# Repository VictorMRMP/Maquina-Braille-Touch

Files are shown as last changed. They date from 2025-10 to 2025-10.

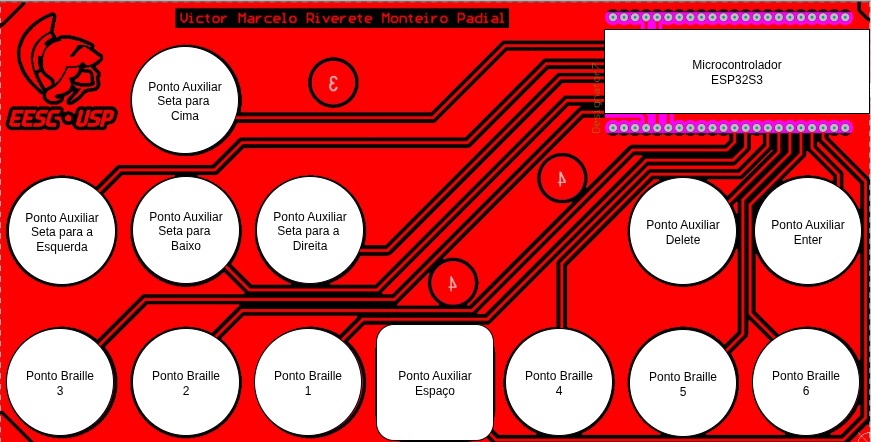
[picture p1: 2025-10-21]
Posição dos pontos.png

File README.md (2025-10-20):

# Teclado Touch Braille (TCC)

Este repositório contém o código-fonte do projeto de Trabalho de Conclusão de Curso (TCC) intitulado: **"Teclado Touch Braille para auxílio na alfabetização e navegação digital de deficientes visuais sensíveis ao toque e/ou com limitações motoras"**.

* **Autor:** Victor Marcelo Riverete Monteiro Padial
* **Microcontrolador:** ESP32-S3
* **Comunicação:** USB HID (Teclado)

## Objetivo do Projeto

O objetivo deste projeto é um teclado Braille totalmente funcional, construído com sensores capacitivos (touch) e um microcontrolador ESP32-S3. O sistema é projetado para ler as combinações de 6 pontos da cela Braille e 7 teclas auxiliares (setas, espaço, enter, apagar), convertendo-as em caracteres digitais.

O principal diferencial deste projeto é o suporte nativo à **Grafia Braille para a Língua Portuguesa**, permitindo a digitação correta de caracteres acentuados (como `á`, `é`, `ç`, `ã`) e símbolos do padrão ABNT.

## Funcionamento

O firmware utiliza o FreeRTOS do ESP32 para dividir o processamento em duas tarefas principais, rodando em núcleos separados:

1.  **`processBraille` (Núcleo 0)**: Esta tarefa é responsável por ler os 6 pinos de toque que compõem a cela Braille. Ela aguarda um tempo (`readingDelay`) para estabilizar a leitura e então processa a combinação. O código gerencia estados especiais, como "letra maiúscula" e "número", e utiliza mapas (`std::map`) para traduzir a combinação Braille no caractere correspondente.
2.  **`processAux` (Núcleo 1)**: Esta tarefa lê os 7 pinos de toque auxiliares. Ela identifica comandos de navegação (Setas), `Espaço`, `Enter` e `Apagar` e os envia diretamente como comandos de teclado.

### Suporte ao Layout ABNT

Para que o teclado enviasse caracteres acentuados do português (ABNT) corretamente, foi necessário modificar a biblioteca USB padrão do ESP32.

O projeto utiliza uma biblioteca `KeyboardUTF8` (baseada na obra de JohnWasser), que foi adaptada para usar o objeto `USBHIDKeyboard` do ESP32. Esta biblioteca utiliza uma tabela de consulta (`Keyboard_BR_1.h`) que mapeia caracteres Unicode (como `0xE1` para `á`) para a sequência correta de teclas ABNT (ex: pressionar "acento agudo", soltar, pressionar "a").

Os arquivos `USBHIDKeyboard.cpp` e `.h` originais do ESP32 foram modificados para suportar este envio no formato ABNT ao invés do US-ASCII padrão.

## Estrutura dos Arquivos

* `MaquinaBrailleTouchFinal.ino`:
    * Código principal do teclado Braille.
    * Contém a lógica de inicialização das tarefas (FreeRTOS), os mapas de caracteres Braille-para-Português, os mapas das teclas auxiliares e a lógica de processamento de toque para ambas as tarefas.
    * Instancia os objetos `USBHIDKeyboard` (nível baixo) e `KeyboardUTF8` (nível alto/ABNT).

* `TesteDeToque.ino`:
    * Um sketch auxiliar de diagnóstico.
    * Ele é usado para calibrar os sensores de toque. O código lê todos os 13 pinos capacitivos e exibe seus valores "base" e a "diferença" (delta) quando tocados, facilitando a definição dos valores de `baseCapacitance` e `thresholdTouch` usados no arquivo `.ino` principal.

* `USBHIDKeyboard.h` e `USBHIDKeyboard.cpp`:
    * **Arquivos de biblioteca modificados.**
    * Substituem os arquivos padrão da biblioteca USB do ESP32.
    * A modificação principal é a remoção do mapa de caracteres US-ASCII padrão.

* `KeyboardUTF8.h` e `KeyboardUTF8.cpp`:
    * **Novos arquivos de biblioteca.**
    * Adaptação da biblioteca `KeyboardUTF8` para ser compatível com a `USBHIDKeyboard` do ESP32.
    * Recebe um caractere Unicode (ex: 'ç') e usa as tabelas de layout para enviá-lo como comandos de teclado.

* `Keyboard_BR_1.h`:
    * **Novo arquivo de biblioteca (Layout).**
    * Contém as tabelas de consulta (lookup tables) para o layout Português-Brasil ABNT.
    * Define o código de tecla (`keycode`) e os modificadores (`MOD_SHIFT`, `MOD_ALTGR`) para cada caractere, incluindo acentos e símbolos.

## Como Usar e Instalar

1.  **Hardware:**
    * Conecte os 13 sensores capacitivos aos pinos do ESP32-S3 conforme definido nos arrays `touchPins` e `auxPins` em `MaquinaBrailleTouchFinal.ino`.

2.  **Calibração (Opcional, mas recomendado):**
    * Carregue o sketch `TesteDeToque.ino` no ESP32-S3.
    * Abra o Monitor Serial (baud 9600).
    * Anote os valores médios dos pinos sem toque (exibidos na calibração inicial). Estes serão seus valores `baseCapacitanceTouch` e `baseCapacitanceAux`.
    * Toque em cada sensor e anote o valor `Δ` (diferença). Escolha um valor seguro para o `thresholdTouch` (ex: `1000`, como no código).
    * Atualize os valores de calibração no início do `MaquinaBrailleTouchFinal.ino`.

3.  **Instalação da Biblioteca ABNT (Crucial):**
    * Encontre o diretório de instalação da biblioteca `USB` do ESP32. O caminho provável é:
        `.../ArduinoData/packages/esp32/hardware/esp32/2.0.14/libraries/USB/src`
    * **Faça backup** dos arquivos `USBHIDKeyboard.h` e `USBHIDKeyboard.cpp` originais.
    * Copie os arquivos `USBHIDKeyboard.h` e `USBHIDKeyboard.cpp` deste repositório para a pasta `src`, substituindo os originais.
    * Copie os arquivos `KeyboardUTF8.h`, `KeyboardUTF8.cpp`, e `Keyboard_BR_1.h` para esta **mesma** pasta `src`.

4.  **Carregar Firmware Principal:**
    * Abra o arquivo `MaquinaBrailleTouchFinal.ino` no seu Arduino IDE.
    * Compile e carregue o código para o ESP32-S3.
    * O dispositivo será reconhecido pelo sistema operacional como um teclado USB padrão e estará pronto para uso.

## Créditos

* A implementação do layout ABNT/UTF-8 é uma adaptação do trabalho original de **JohnWasser** (disponível em [Arduino\_KeyboardUTF8](https://github.com/JohnWasser/Arduino_KeyboardUTF8)).

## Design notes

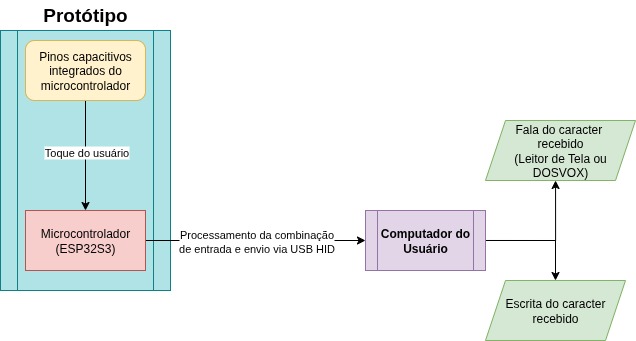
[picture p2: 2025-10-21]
Diagrama Hardware.jpeg

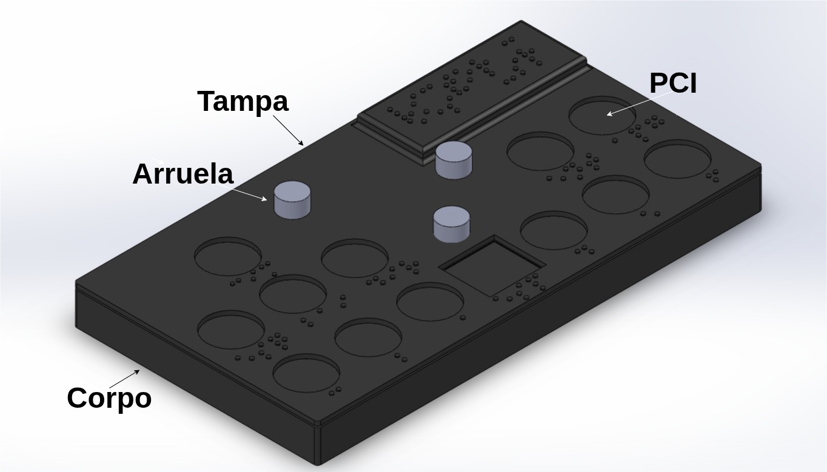
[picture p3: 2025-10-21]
Case3D.png

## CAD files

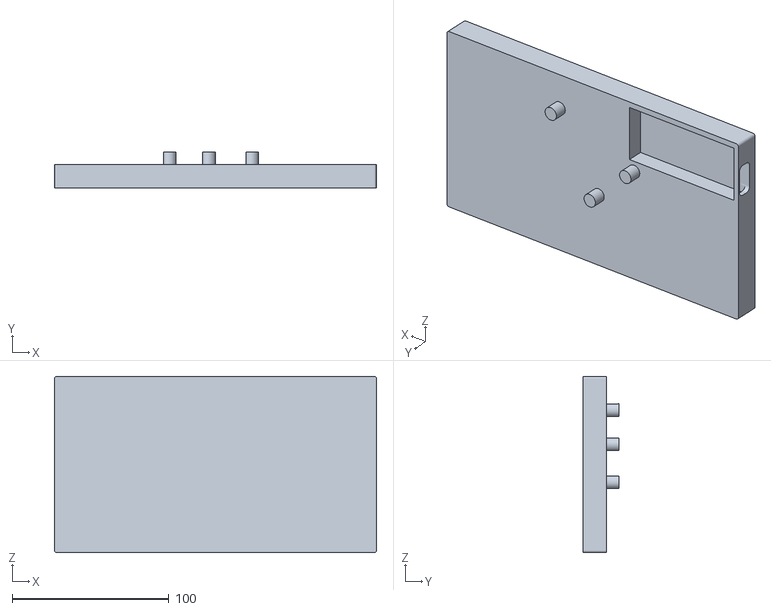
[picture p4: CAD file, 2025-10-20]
PCI/Bottom.STL
205.7 x 23.0 x 112.6

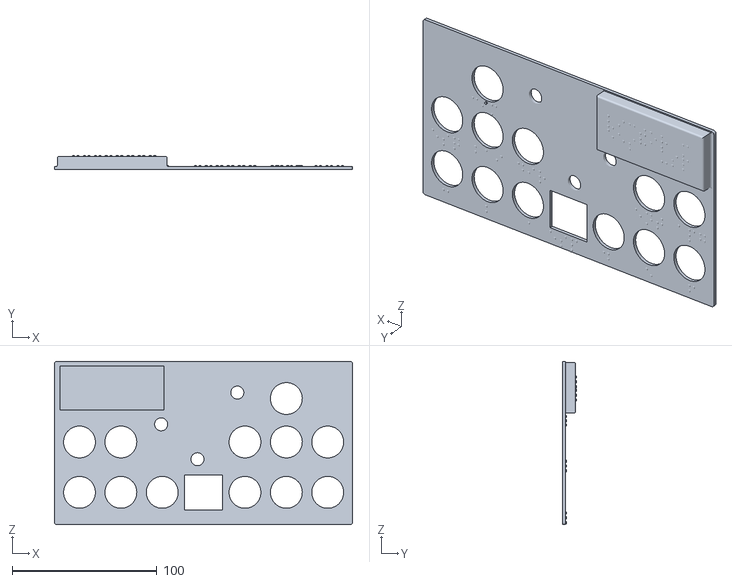
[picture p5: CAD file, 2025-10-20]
PCI/Top.STL
205.6 x 9.65 x 112.6

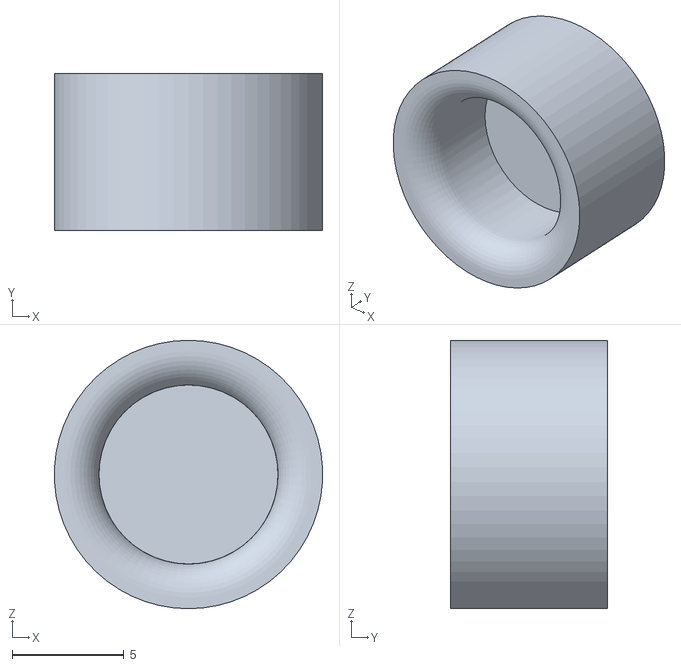
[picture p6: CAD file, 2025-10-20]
PCI/Screw.STL
12.0 x 7.00 x 12.0

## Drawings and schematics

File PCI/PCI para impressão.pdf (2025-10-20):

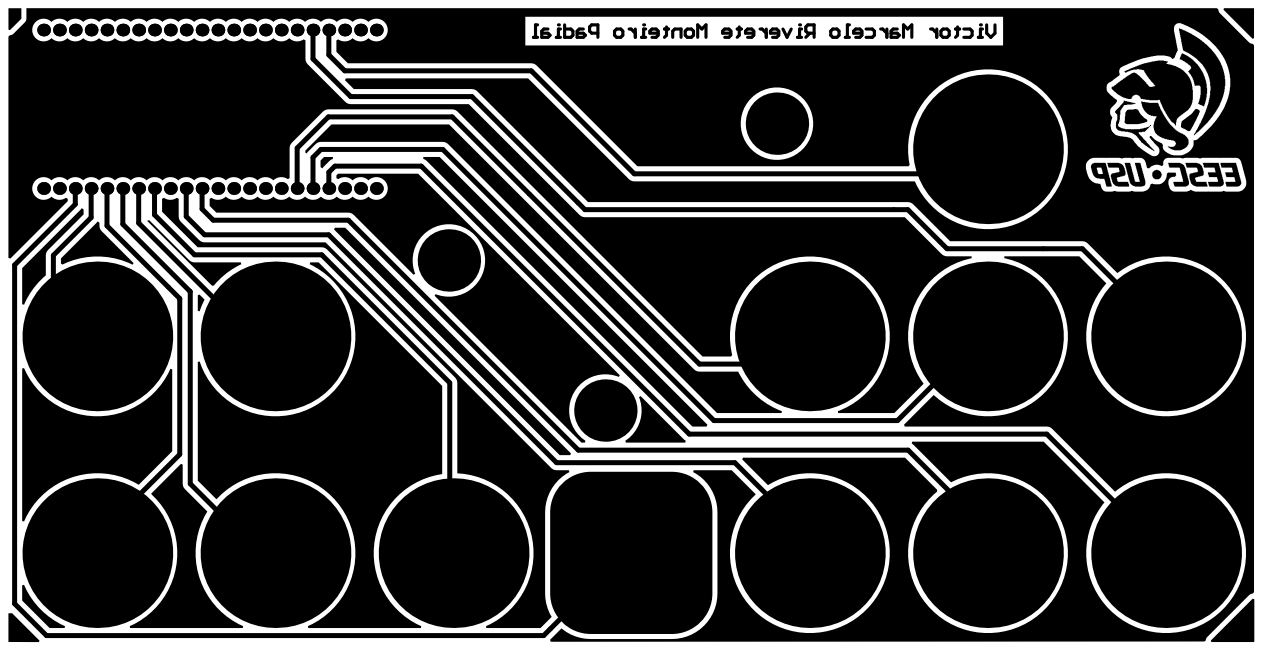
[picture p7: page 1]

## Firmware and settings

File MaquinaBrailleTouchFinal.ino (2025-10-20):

// =======================================================================
// Autor: Victor Marcelo Riverete Monteiro Padial
// Descrição desse código: Identifica as combinações Braille e comandos auxiliares e transforma em caracteres correspondentes de acordo com a Grafia Braille para a Lingua Portuguesa
// Microcontrolador: ESP32S3
// Comunicação: Porta USB HID
// Versão: 3.0
// Projeto: "Teclado Touch Braille para auxílio na alfabetização e navegação digital de deficientes visuais sensíveis ao toque e/ou com limitações motoras", realizado para o Trabalho de Conclusão de Curso para o curso de Engenharia Elétrica com ênfase em eletrônica da Universidade de São Paulo(USP) do Departamento de Engenharia Elétrica e Computação de São Carlos(SEL)
// =======================================================================

#include <map>
#include <cctype>
#include "freertos/FreeRTOS.h"
#include "freertos/task.h"
#include "USB.h"
#include "USBHIDKeyboard.h"

// MUDANÇA: Inclui os arquivos da biblioteca ABNT que devem estar no mesmo caminho que a biblioteca USBHIDKeyboard.h, provavelmente em .../ArduinoData/packages/esp32/hardware/esp32/2.0.14/libraries/USB/src
#include "KeyboardUTF8.h"
#include "Keyboard_BR_1.h" // Agora só contém as tabelas

// MUDANÇA: Instancia os DOIS objetos
// 1. O objeto HID de baixo nível 
USBHIDKeyboard Braille_Keyboard;

// 2. O objeto tradutor ABNT, passando o objeto HID para ele.
//    Ele usará as tabelas de 'Keyboard_BR_1.h' e enviará os 
//    comandos através do 'Braille_Keyboard'.
KeyboardUTF8 Braille_ABNT(
    kbdbr_1, sizeof kbdbr_1 / sizeof kbdbr_1[0], 
    kbdbr_1_deadkeys, sizeof kbdbr_1_deadkeys / sizeof kbdbr_1_deadkeys[0],
    Braille_Keyboard // 
);


//Ordem dos bits (i=0 a 5) para corresponder ao mapa: P6, P5, P4, P1, P2, P3
const int touchPins[] = {12, 11, 9, 3, 8, 4}; 

//Ordem dos bits (i=0 a 6) para corresponder ao mapa: Dir, Baixo, Cima, Esq, Esp, Enter, Apagar
const int auxPins[] = {6, 5, 1, 2, 14, 10, 13}; 

const int numTouchPins = 6;
const int numAuxPins = 7;

// Constantes de calibração (sem mudanças)
int baseCapacitanceTouch[numTouchPins]={764,828,1008,756,720,692};
int baseCapacitanceAux[numAuxPins]={596,630,712,673,635,544,644};
const int thresholdTouch = 1000;
int measurement = 10; 
int slep = 10; 

const int letra_maiscula = 0b000101; 
const int numero = 0b100111;

// Mapa principal de Braille para caracteres
std::map<int, uint8_t> braille_char_map = {
    // Letras (sem mudanças)
    {0b001000, 'a'}, {0b011000, 'b'}, {0b001100, 'c'}, {0b001110, 'd'},
    {0b001010, 'e'}, {0b011100, 'f'}, {0b011110, 'g'}, {0b011010, 'h'},
    {0b010100, 'i'}, {0b010110, 'j'}, {0b101000, 'k'}, {0b111000, 'l'},
    {0b101100, 'm'}, {0b101110, 'n'}, {0b101010, 'o'}, {0b111100, 'p'},
    {0b111110, 'q'}, {0b111010, 'r'}, {0b110100, 's'}, {0b110110, 't'},
    {0b101001, 'u'}, {0b111001, 'v'}, {0b010111, 'w'}, {0b101101, 'x'},
    {0b101111, 'y'}, {0b101011, 'z'},

    // Letras acentuadas (sem mudanças)
    {0b111011, 0xE1}, // 'á'
    {0b111111, 0xE9}, // 'é'
    {0b100100, 0xED}, // 'í'
    {0b100101, 0xF3}, // 'ó'
    //{0b110111, 0xFA}, // 'ú' não funcionando
    {0b011101, 0xE0}, // 'à'
    {0b001001, 0xE2}, // 'â'
    {0b011001, 0xEA}, // 'ê'
    {0b001111, 0xF4}, // 'ô'
    {0b100110, 0xE3}, // 'ã'
    {0b010101, 0xF5}, // 'õ'
    {0b111101, 0xE7}, // 'ç'

    // Sinais especiais (sem mudanças - Braille_ABNT vai traduzir)
    {0b010000, ','}, {0b110000, ';'}, {0b010010, ':'}, {0b100000, '.'},
    {0b010011, '/'}, {0b010001, '?'}, {0b100001, '-'}, {0b100010, '*'},
    {0b110001, '"'}, {0b000011, '$'}, {0b110010, '+'}, {0b110011, '='},
    {0b000111, '>'},
    
    // MUDANÇA: Corrigido para ABNT2 usando os códigos de caractere reais
    // A biblioteca Braille_ABNT saberá como digitar isso.
    {0b100011, 0xBA}, // 'º' (código Unicode/Latin-1)
    {0b011011, 0xB4}, // '´' (código Unicode/Latin-1 para acento agudo)

    // Prefixos (sem mudanças)
    {letra_maiscula, 0x16},
    {numero, 0x17}
};

// Mapa para o modo "Número" (sem mudanças)
std::map<int, uint8_t> braille_number_map = {
    {0b001000, '1'}, {0b011000, '2'}, {0b001100, '3'}, {0b001110, '4'},
    {0b001010, '5'}, {0b011100, '6'}, {0b011110, '7'}, {0b011010, '8'},
    {0b010100, '9'}, {0b010110, '0'} 
};

// Mapa para pinos auxiliares (sem mudanças)
std::map<int, int> aux_map = {
    {0b0000001, KEY_RIGHT_ARROW},
    {0b0000010, KEY_DOWN_ARROW}, 
    {0b0000100, KEY_UP_ARROW},   
    {0b0001000, KEY_LEFT_ARROW}, 
    {0b0010000, 0x20},           // Espaço (ASCII)
    {0b0100000, KEY_RETURN},     
    {0b1000000, KEY_BACKSPACE},  
};

bool useShift = false;
bool useNumber = false;

// Variáveis de tempo (sem mudanças)
unsigned long lastReadingTimeBraille = 0;
unsigned long lastReadingTimeAux = 0;

const unsigned long readingDelay = 750;
const unsigned long readingDelayAux = 500;

// Prototipação
void processBraille(void *pvParameters);
void processAux(void *pvParameters);

void setup() {
    Serial.begin(9600);
    delay(100);
    Braille_Keyboard.begin();
    
    USB.begin();
    touchSetCycles(measurement, slep);
    xTaskCreatePinnedToCore(processBraille, "ProcessBraille", 4096, NULL, 1, NULL, 0);
    xTaskCreatePinnedToCore(processAux, "ProcessAux", 4096, NULL, 1, NULL, 1);
}

void loop() {
    // Loop vazio, tarefas executadas pelo RTOS
}

void processBraille(void *pvParameters) {
    while (true) {
        int braille = 0;
        for (int i = 0; i < numTouchPins; i++) {
            int touchValue = touchRead(touchPins[i]);
            if (touchValue - baseCapacitanceTouch[i] > thresholdTouch) {
                braille |= (1 << i);
            }
        }

        if (braille > 0 && (millis() - lastReadingTimeBraille > readingDelay)) {
            lastReadingTimeBraille = millis(); 
            Serial.printf("Braille lido: %d\n", braille);

            if (braille == letra_maiscula) {
                useShift = true;
            } else if (braille == numero) {
                useNumber = true;
            } else {
                uint8_t output = 0;
                if (useNumber) {
                    auto it = braille_number_map.find(braille);
                    if (it != braille_number_map.end()) output = it->second;
                    useNumber = false;
                } else {
                    auto it = braille_char_map.find(braille);
                    if (it != braille_char_map.end()) output = it->second;

                    if (useShift) {
                        if (islower(output)) output = toupper(output);
                        useShift = false;
                    }
                }

                    if (output) {
                    // 1. Envia o caractere ABNT (que pode pressionar e soltar SHIFT)
                    Braille_ABNT.writeUnicode(output);

                    // Força a liberação de TODAS as teclas (incluindo SHIFT)
                    // para garantir que ele não fique "preso".
                    Braille_Keyboard.releaseAll();
                }
            }
        }

        vTaskDelay(100 / portTICK_PERIOD_MS);
    }
}

void processAux(void *pvParameters) {
    while (true) {
        int aux = 0;
        for (int i = 0; i < numAuxPins; i++) {
            int touchValue = touchRead(auxPins[i]);
            if (touchValue - baseCapacitanceAux[i] > thresholdTouch) {
                aux |= (1 << i);
            }
        }

        if (aux > 0 && (millis() - lastReadingTimeAux > readingDelayAux)) {
            lastReadingTimeAux = millis(); 

            auto it = aux_map.find(aux);
            if (it != aux_map.end()) {

                Braille_Keyboard.write(it->second);
            }
        }
        
        vTaskDelay(100 / portTICK_PERIOD_MS);
    }
}

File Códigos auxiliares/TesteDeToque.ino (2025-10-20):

// =======================================================================
// Autor: Victor Marcelo Riverete Monteiro Padial
// Descrição desse código: Teste dos pinos capacitivos para verificação do toque a partir da mudança de capacitância
// Microcontrolador: ESP32S3
// Comunicação: Porta Serial COM
// Versão: 1.0
// Projeto: "Teclado Touch Braille para auxílio na alfabetização e navegação digital de deficientes visuais sensíveis ao toque e/ou com limitações motoras", realizado para o Trabalho de Conclusão de Curso para o curso de Engenharia Elétrica com ênfase em eletrônica
// =======================================================================

// --- CONFIGURAÇÕES DOS PINOS ---
const int ACTIVE_TOUCH_PINS[] = {
    // Pinos Braille (6)
    //Pino 3 2 1 4 5 6
           4, 8, 3, 9, 11, 12,
    // Pinos Esq Baixo Dir Cima Esp Enter Apagar
              2,   5,    6, 1,   14, 10   , 13
};
const char* PIN_LABELS[] = {
  "B_Ponto3", "B_Ponto2", "B_Ponto1", "B_Ponto4", "B_Ponto5", "B_Ponto6",
  "Esq", "Baixo", "Dir", "Cima", "Esp", "Enter", "Apagar"
};

// --- CONFIGURAÇÕES DO SENSOR DE TOQUE ---
#define TOUCH_MEAS_CYCLE 10   // Ciclo de medição (↑ = mais sensível)
#define TOUCH_SLEEP_CYCLE 10   // Ciclo de descanso
#define PLOT_INTERVAL_MS 3000   // Intervalo entre leituras
#define BASELINE_SMOOTHING 0.9 // Fator de calibração dinâmica (0.0–1.0)
#define TOUCH_THRESHOLD 1000     // Sensibilidade de toque (ajuste se necessário)

const int NUM_ACTIVE_PINS = sizeof(ACTIVE_TOUCH_PINS) / sizeof(ACTIVE_TOUCH_PINS[0]);

// --- VARIÁVEIS GLOBAIS ---
long baselineValues[NUM_ACTIVE_PINS];
unsigned long previousMillis = 0;

// =======================================================================
//   SETUP
// =======================================================================
void setup() {
  Serial.begin(9600);
  delay(1000);

  Serial.println("\n=== Analisador de Resposta Capacitiva (v4.0) ===");
  Serial.println("Configuração de alta sensibilidade e calibração dinâmica.");
  Serial.println("Não toque na placa durante a calibração inicial!\n");

  // Configuração de sensibilidade
  touchSetCycles(TOUCH_MEAS_CYCLE, TOUCH_SLEEP_CYCLE);

  // Calibração inicial
  for (int i = 0; i < NUM_ACTIVE_PINS; i++) {
    baselineValues[i] = touchRead(ACTIVE_TOUCH_PINS[i]);
    delay(30);
  }

  Serial.println(">>> Calibração inicial concluída! <<<");
  Serial.println("Leituras iniciadas...\n");

  // Cabeçalho da tabela
  for (int i = 0; i < NUM_ACTIVE_PINS; i++) {
    Serial.print(PIN_LABELS[i]);
    Serial.print("\t");
  }
  Serial.println();
}

// =======================================================================
//   LOOP
// =======================================================================
void loop() {
  if (millis() - previousMillis >= PLOT_INTERVAL_MS) {
    previousMillis = millis();

    bool plotterMode = false; // Troque para true se quiser usar o Plotter Serial

    if (!plotterMode) Serial.println("\n--- Leitura Atual ---");

    for (int i = 0; i < NUM_ACTIVE_PINS; i++) {
      long currentValue = touchRead(ACTIVE_TOUCH_PINS[i]);
      long diff = baselineValues[i] - currentValue;

      // Calibração dinâmica (mantém baseline atualizado lentamente)
      baselineValues[i] = BASELINE_SMOOTHING * baselineValues[i] + 
                          (1.0 - BASELINE_SMOOTHING) * currentValue;

      if (!plotterMode) {
        Serial.print(PIN_LABELS[i]);
        Serial.print(": ");
        Serial.print(currentValue);
        Serial.print(" (Δ=");
        Serial.print(diff);
        Serial.print(") ");
        if (diff > TOUCH_THRESHOLD) Serial.print("→ TOQUE DETECTADO");
        Serial.println();
      } else {
        Serial.print(PIN_LABELS[i]);
        Serial.print(":");
        Serial.print(diff);
        Serial.print("\t");
      }
    }

    if (plotterMode) Serial.println(); // Quebra de linha para o plotter
  }
}

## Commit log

2025-10-20 Add capacitive touch testing code for ESP32S3
    This code implements capacitive touch pin testing for an ESP32S3 microcontroller, including setup and loop functions for reading touch inputs and calibrating sensitivity.
2025-10-21 Rename PCB2.png to Posição dos pontos.png
